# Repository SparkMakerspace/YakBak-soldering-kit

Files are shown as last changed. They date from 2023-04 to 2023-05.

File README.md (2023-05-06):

---
layout: page
title: YakSpark Soldering Kit
permalink: /index.html
---

## About
This project is intended to act as a short introduction to soldering, as well as to act as a platform for exploring audio inputs/outputs with Arduino.

## Components
* Seeed Studio XIAO ESP32C3 ([source](https://www.seeedstudio.com/Seeed-XIAO-ESP32C3-p-5431.html))
* Electret Microphone Amp Module (or clone)
* Adafruit 2130 - PAM8302 (or clone)
* 10Ω resistor (THT)
* 100nf ceramic capacitor
* 8Ω 0.5W Speaker ([source](https://www.harfington.com/products/p-1077007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))

## Assembly
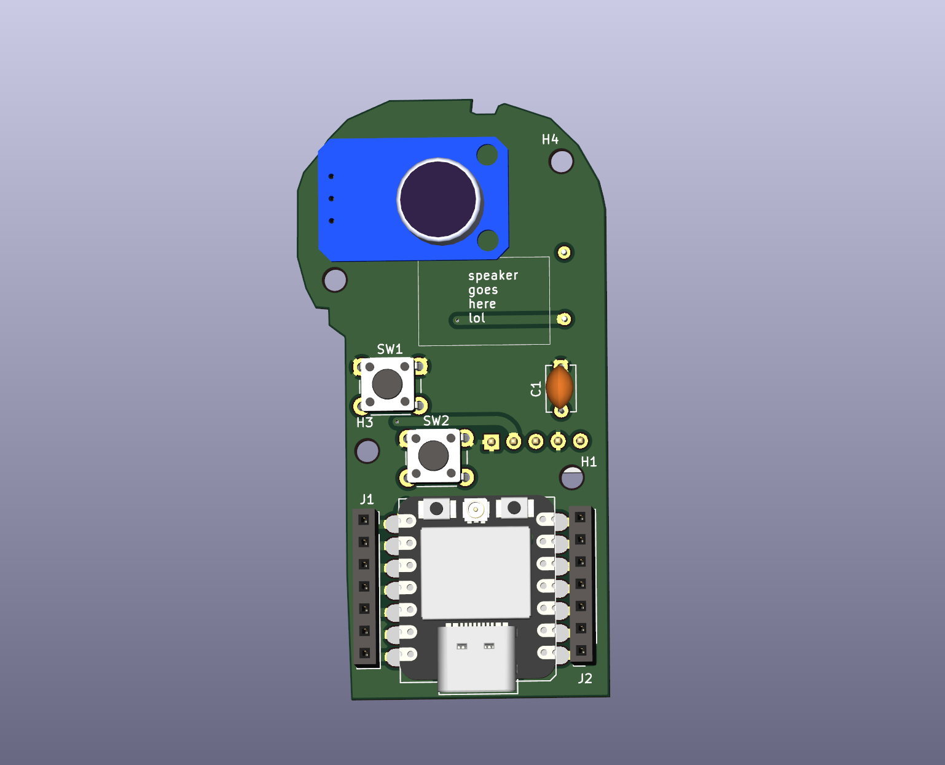
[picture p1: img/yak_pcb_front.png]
YakSpark front

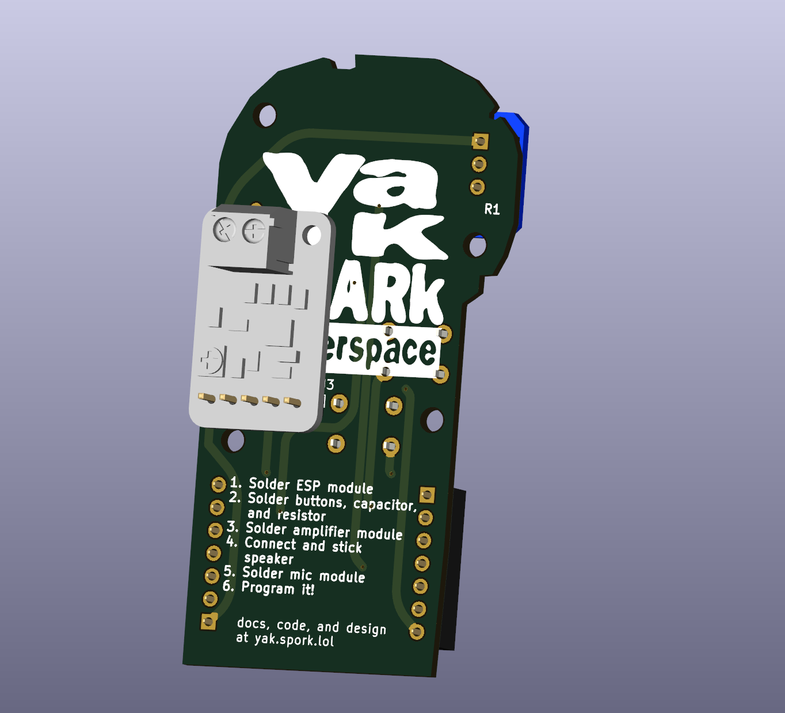
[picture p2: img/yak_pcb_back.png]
YakSpark back


## PCB
The PCB for this project was designed in KiCAD 7.

## Code
Download this repository and open the [software](https://github.com/SparkMakerspace/YakBak-soldering-kit/tree/main/software/test%20software) directory to find the firmware source. The firmware is intended to be modified and flashed with [PlatformIO](https://platformio.org/).

## Enclosure
The YakSpark enclosure is intended to be 3D printed and was designed in FreeCAD. Source, STEP, and STL files are found in the [enclosure](https://github.com/SparkMakerspace/YakBak-soldering-kit/tree/main/enclosure) directory. 
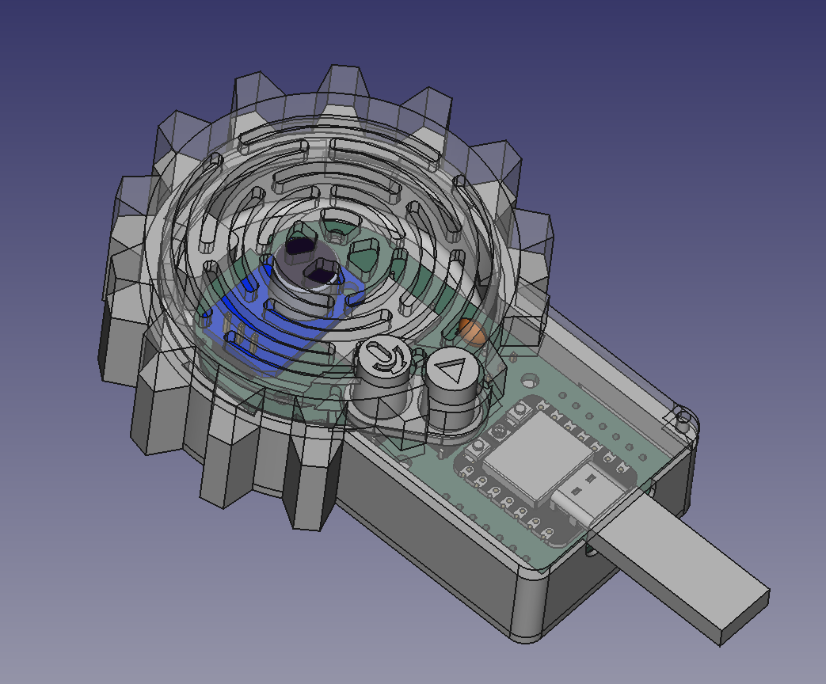
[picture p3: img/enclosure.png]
enclosure


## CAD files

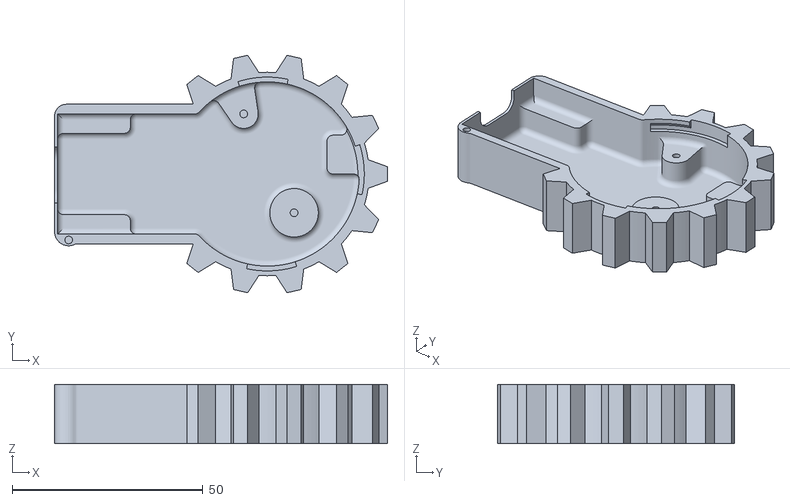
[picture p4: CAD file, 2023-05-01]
enclosure/CAD exports/Yak Spark Assembly v1.0-Lower Case_001.stl
87.3 x 62.2 x 15.5

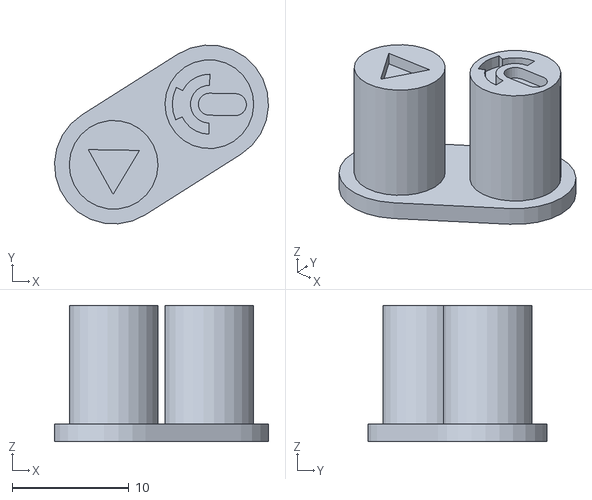
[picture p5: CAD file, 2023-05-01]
enclosure/CAD exports/Yak Spark Assembly v1.0-Buttons_001.stl
18.4 x 15.3 x 11.7

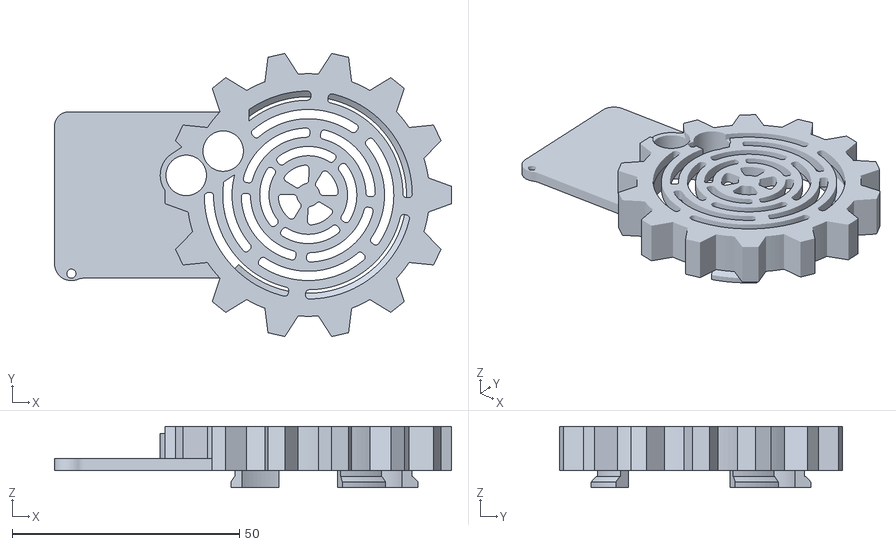
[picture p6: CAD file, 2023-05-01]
enclosure/CAD exports/Yak Spark Assembly v1.0-Upper Case_001.stl
87.3 x 62.2 x 13.5

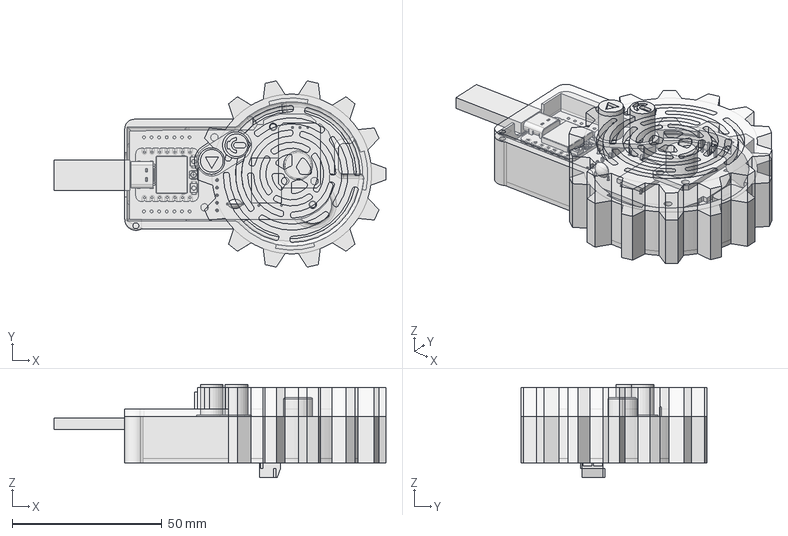
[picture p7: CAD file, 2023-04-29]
enclosure/Yak Spark Assembly v1.0.FCStd
110.9 x 62.2 x 31.2 mm
Lower Case_001
Yak Spark Board_001
Upper Case_001
Buttons_001

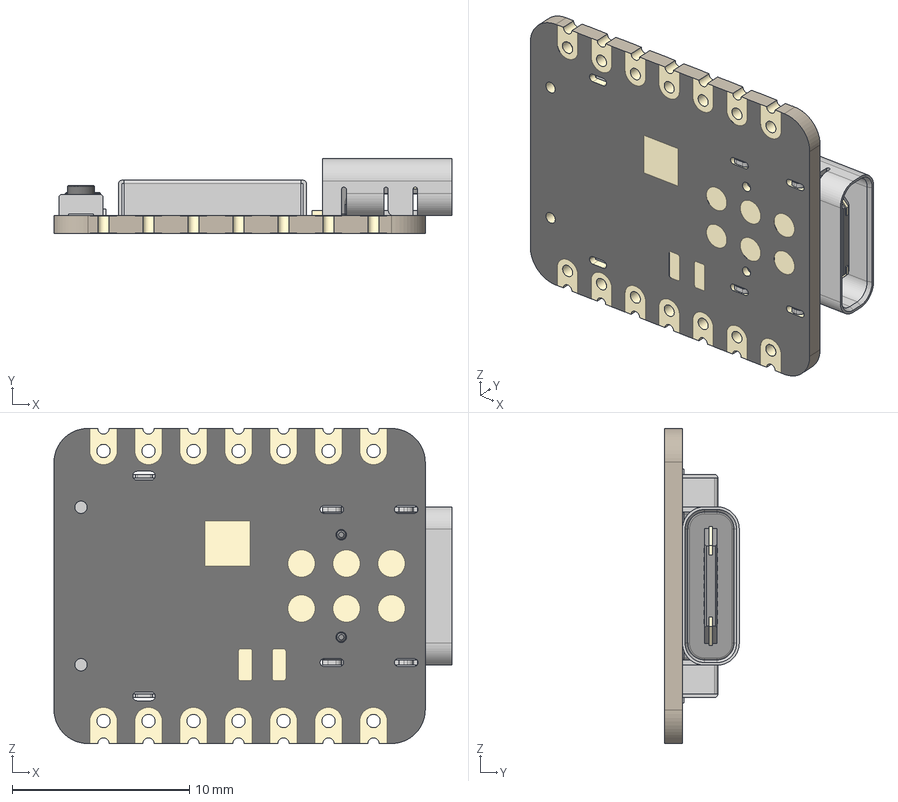
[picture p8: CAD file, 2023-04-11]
3d/Seeed Studio XIAO-ESP32-C3.step
22.5 x 4.21 x 17.8 mm
BOSS-EXTRUDE14_8_
BOSS-EXTRUDE7_4_
BOSS-EXTRUDE7_3_
BOSS-EXTRUDE14_4_
BOSS-EXTRUDE14_2_
BOSS-EXTRUDE14_11_
BOSS-EXTRUDE7_7_
BOSS-EXTRUDE14_9_
BOSS-EXTRUDE14_3_
BOSS-EXTRUDE14_7_
MIRROR2
BOSS-EXTRUDE14_5_
BOSS-EXTRUDE14_12_
BOSS-EXTRUDE7_8_
BOSS-EXTRUDE7_1_
BOSS-EXTRUDE14_10_
BOSS-EXTRUDE7_9_
BOSS-EXTRUDE14_6_
BOSS-EXTRUDE14_1_
BOSS-EXTRUDE7_6_
BOSS-EXTRUDE7_2_
CUT-EXTRUDE5
BOSS-EXTRUDE7_5_
U.FL Connector v1
Button (1) x 2
Shield

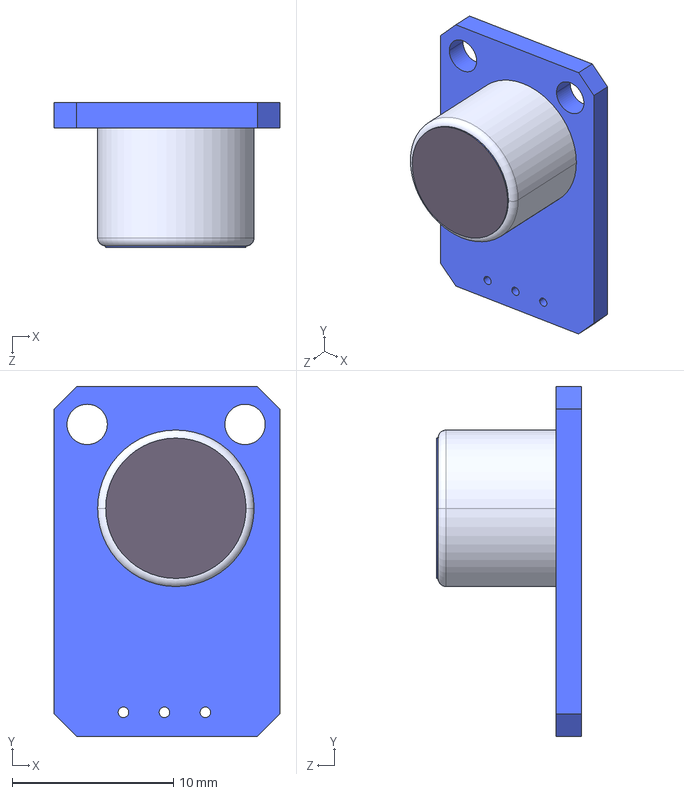
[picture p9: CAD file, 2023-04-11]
3d/max4466_mic_amp.STEP
14.0 x 21.7 x 9.00 mm

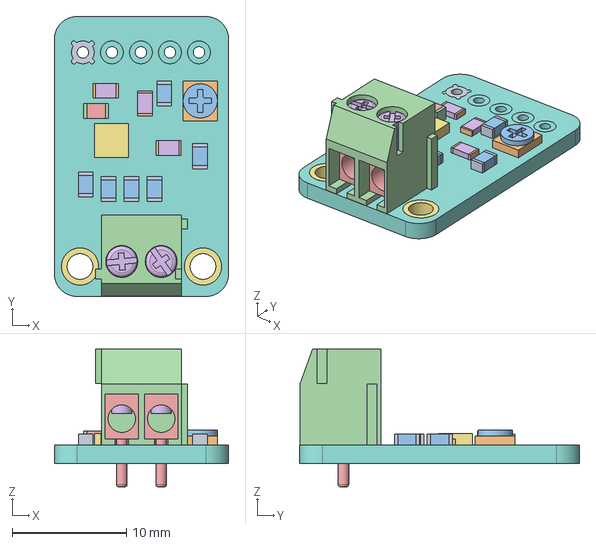
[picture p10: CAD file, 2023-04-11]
3d/adafruit_2130 v1.step
15.3 x 24.5 x 12.1 mm

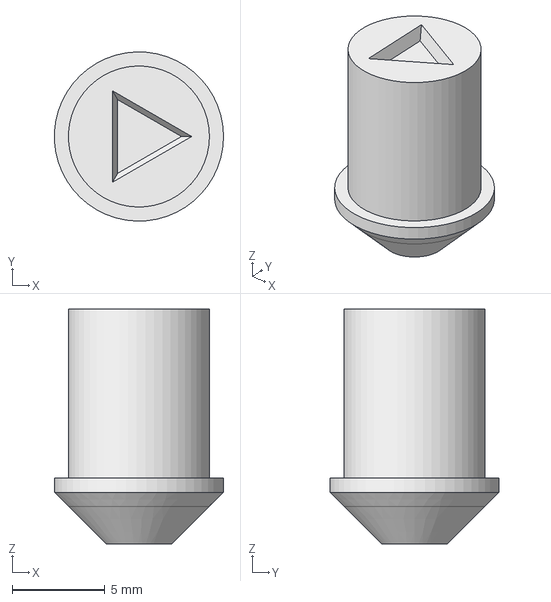
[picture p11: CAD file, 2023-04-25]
enclosure/Play Button.FCStd
9.14 x 9.14 x 12.7 mm

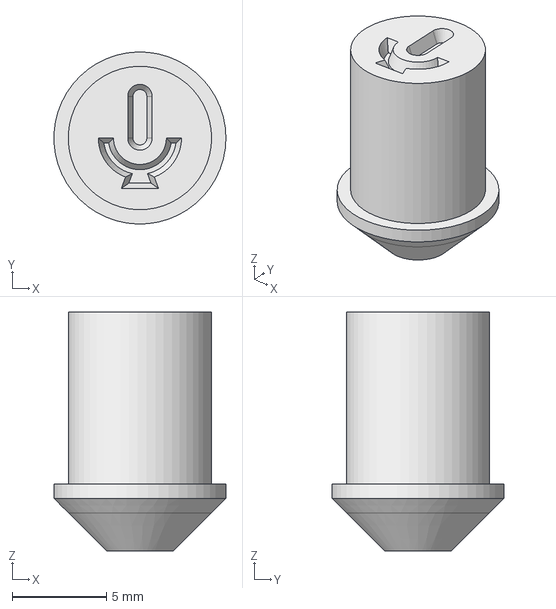
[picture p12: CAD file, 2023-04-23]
enclosure/Record Button.FCStd
9.14 x 9.14 x 12.7 mm

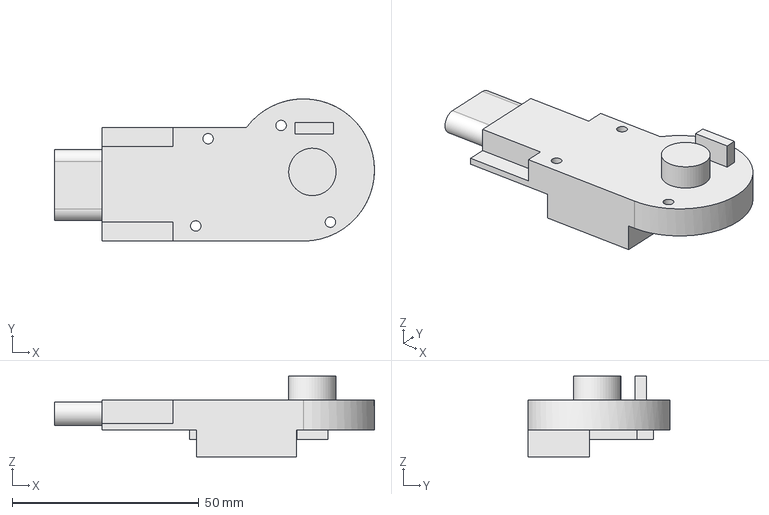
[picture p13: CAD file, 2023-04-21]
enclosure/Space Reservation.FCStd
85.7 x 38.1 x 21.6 mm

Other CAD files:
enclosure/Buttons.FCStd
enclosure/Upper Case.FCStd
enclosure/Lower Case.FCStd
enclosure/CAD exports/Buttons step.step
enclosure/CAD exports/Upper Case step.step
enclosure/CAD exports/Lower Case step.step
enclosure/CAD exports/Play Button Step.step
enclosure/CAD exports/Record Button Step.step
enclosure/CAD exports/Buttons step.stl
enclosure/CAD exports/Lower Case step.stl
enclosure/CAD exports/Upper Case step.stl
enclosure/Yak Spark Board.FCStd

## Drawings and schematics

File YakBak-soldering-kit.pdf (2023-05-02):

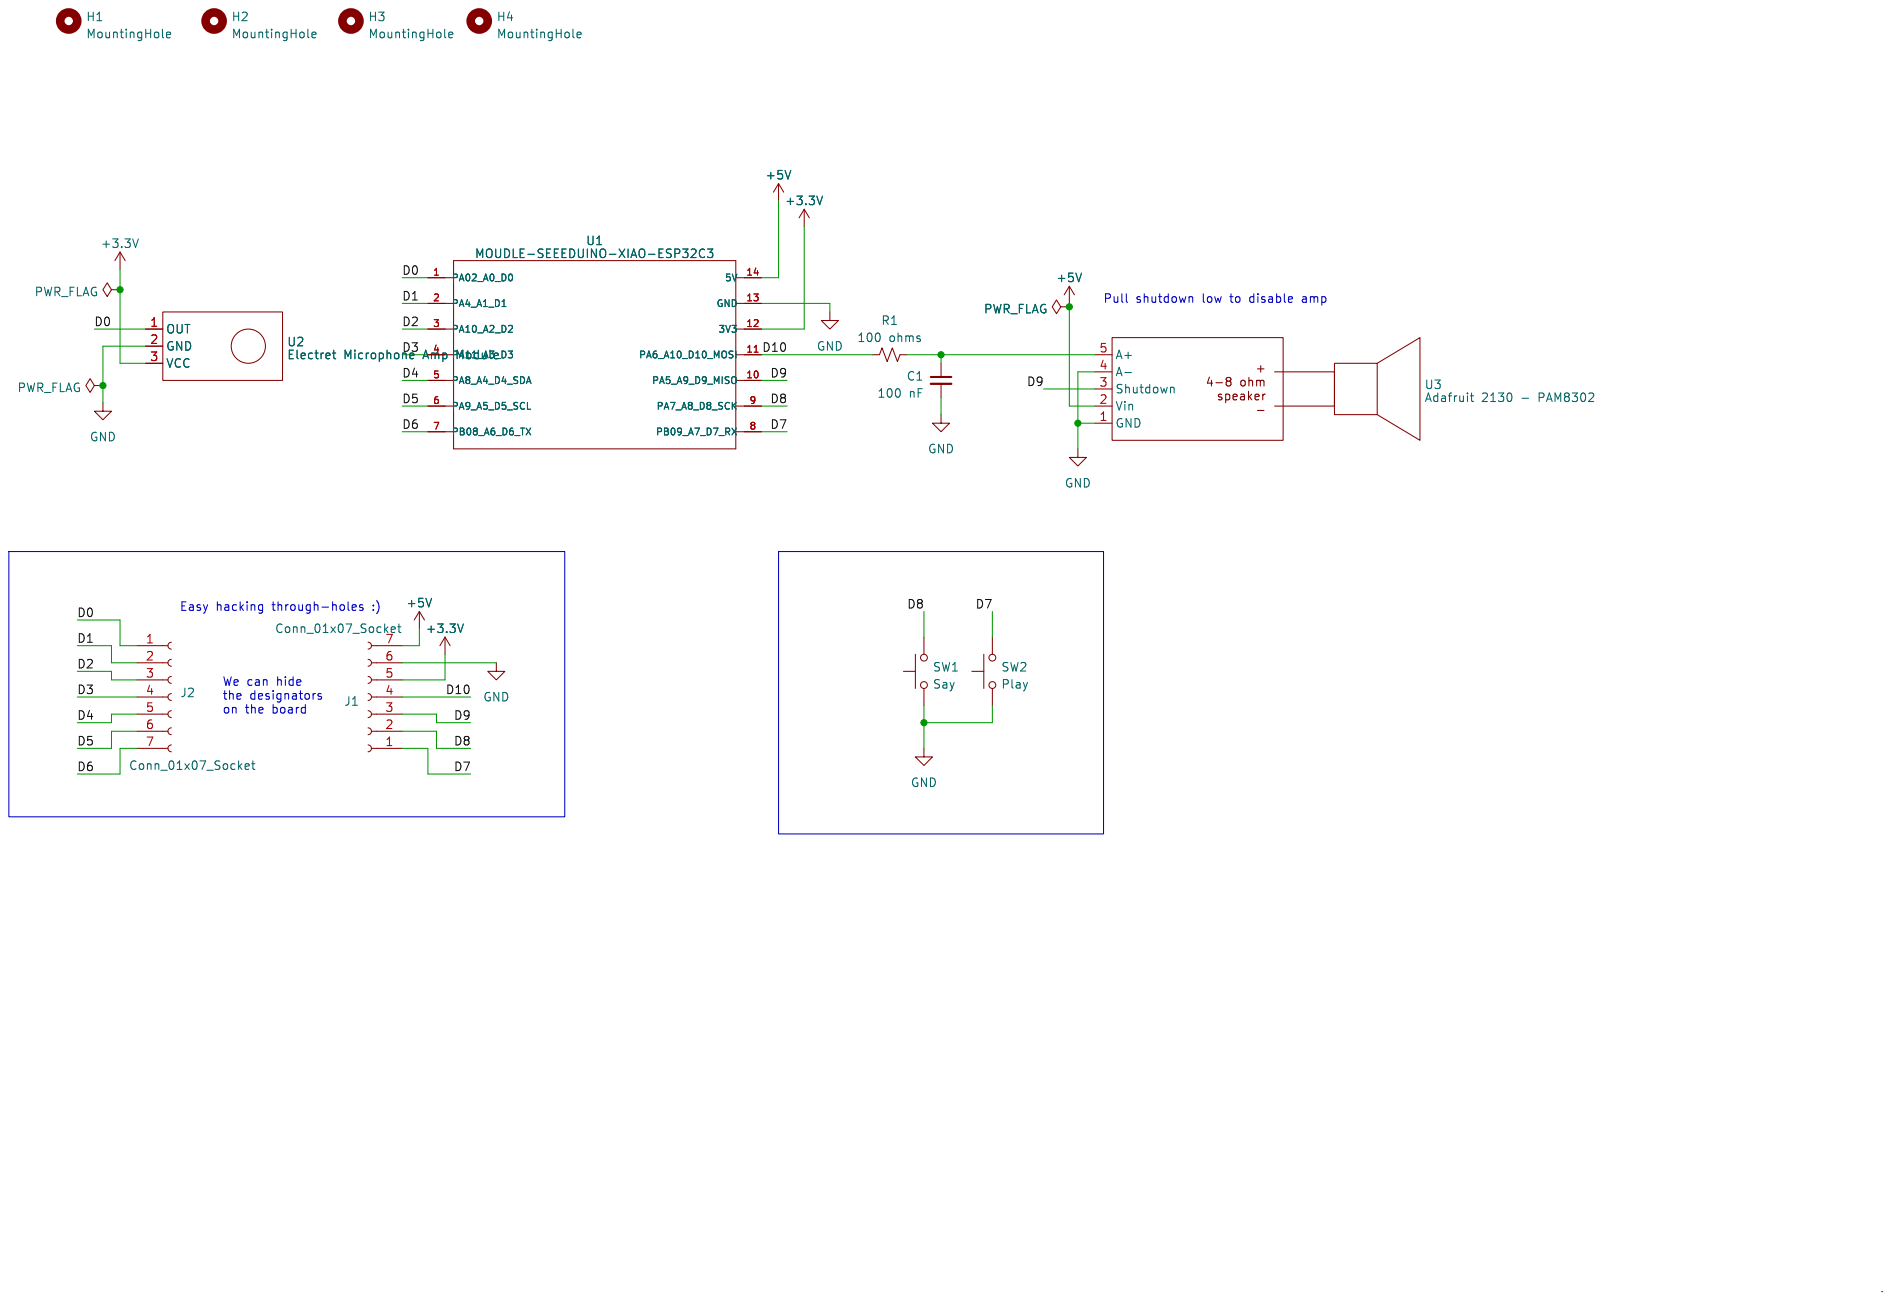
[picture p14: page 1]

the designators on the board

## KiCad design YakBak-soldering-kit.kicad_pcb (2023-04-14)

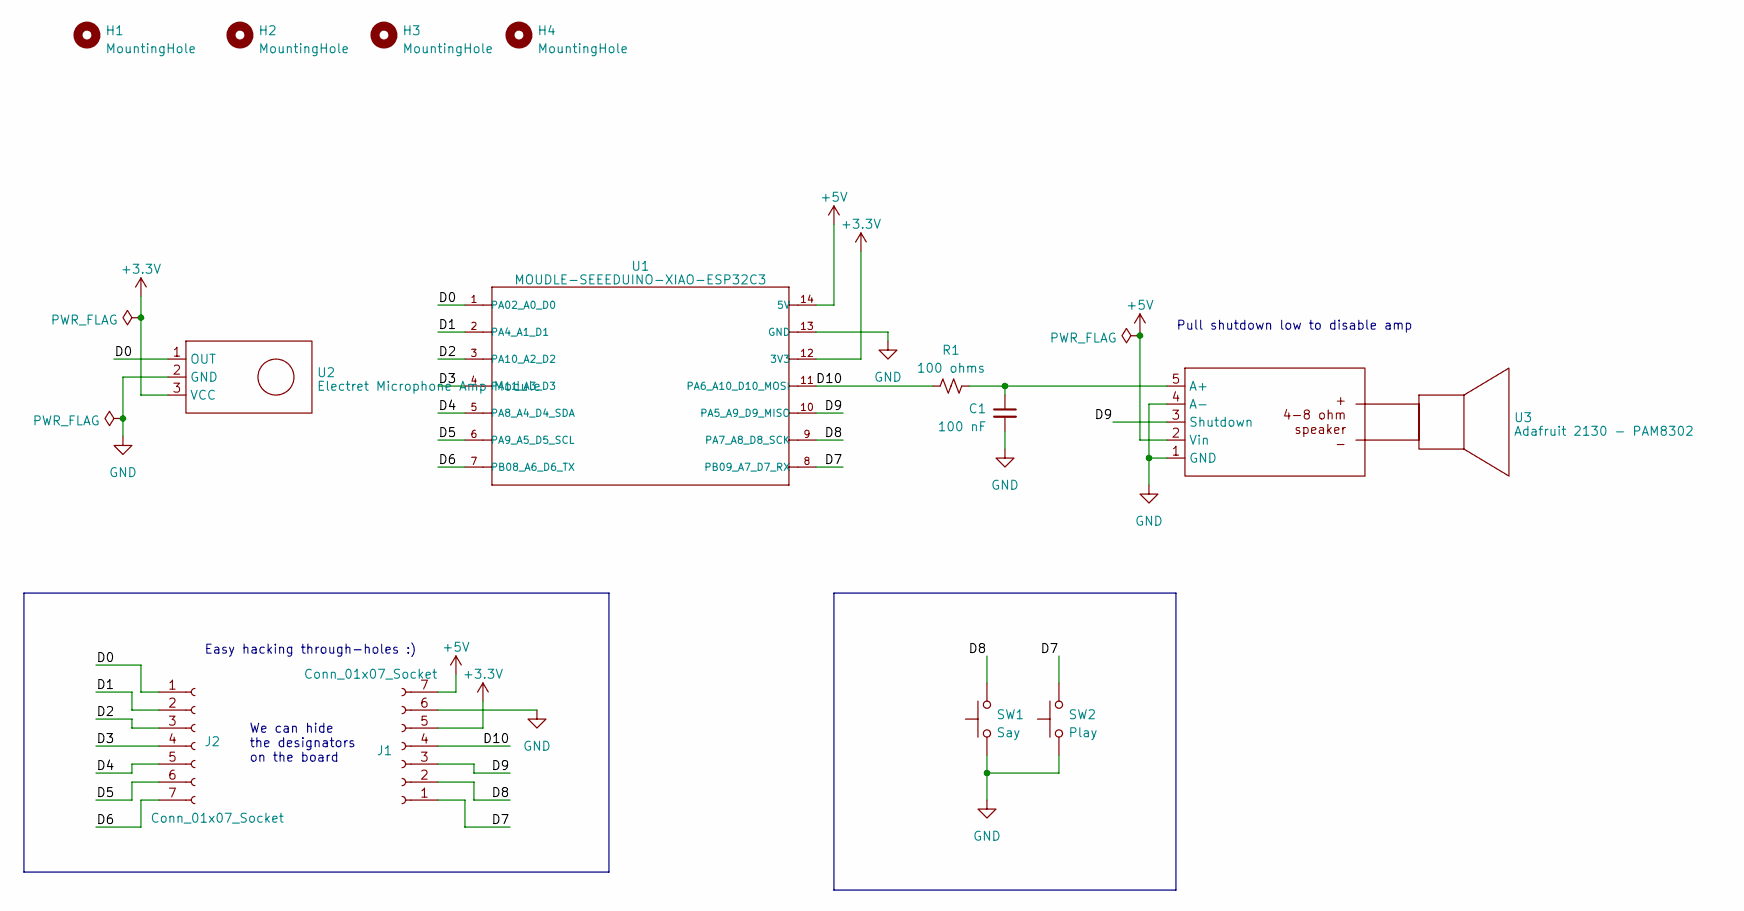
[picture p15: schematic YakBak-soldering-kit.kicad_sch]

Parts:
C1: 100 nF; C_Disc_D5.1mm_W3.2mm_P5.00mm
H1, H2, H3, H4: MountingHole; MountingHole_2.5mm
J1, J2: Conn_01x07_Socket; PinSocket_1x07_P2.54mm_Vertical
R1: 100 ohms; R_Axial_DIN0204_L3.6mm_D1.6mm_P7.62mm_Horizontal
SW1: Say; SW_PUSH_6mm
SW2: Play; SW_PUSH_6mm
U1: MOUDLE-SEEEDUINO-XIAO-ESP32C3; MOUDLE14P-SMD-2.54-21X17.8MM
U2: Electret Microphone Amp Module; PinSocket_1x03_P2.54mm_Vertical
U3: Adafruit 2130 - PAM8302; PinHeader_1x05_P2.54mm_Vertical

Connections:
+3.3V: J1.5, U1.12 (3V3), U2.3 (VCC)
+5V: J1.7, U1.14 (5V), U3.2 (Vin)
/D0: J2.1, U1.1 (PA02_A0_D0), U2.1 (OUT)
/D1: J2.2, U1.2 (PA4_A1_D1)
/D2: J2.3, U1.3 (PA10_A2_D2)
/D3: J2.4, U1.4 (PA11_A3_D3)
/D4: J2.5, U1.5 (PA8_A4_D4_SDA)
/D5: J2.6, U1.6 (PA9_A5_D5_SCL)
/D6: J2.7, U1.7 (PB08_A6_D6_TX)
/D7: J1.1, SW2.2, U1.8 (PB09_A7_D7_RX)
/D8: J1.2, SW1.2, U1.9 (PA7_A8_D8_SCK)
/D9: J1.3, U1.10 (PA5_A9_D9_MISO), U3.3 (Shutdown)
/D10: J1.4, R1.1, U1.11 (PA6_A10_D10_MOSI)
GND: C1.2, J1.6, SW1.1, SW2.1, U1.13 (GND), U2.2 (GND), U3.1 (GND), U3.4 (A-)
unnamed: C1.1, R1.2, U3.5 (A+)

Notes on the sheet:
We can hide the designators on the board
Pull shutdown low to disable amp
Easy hacking through-holes :)

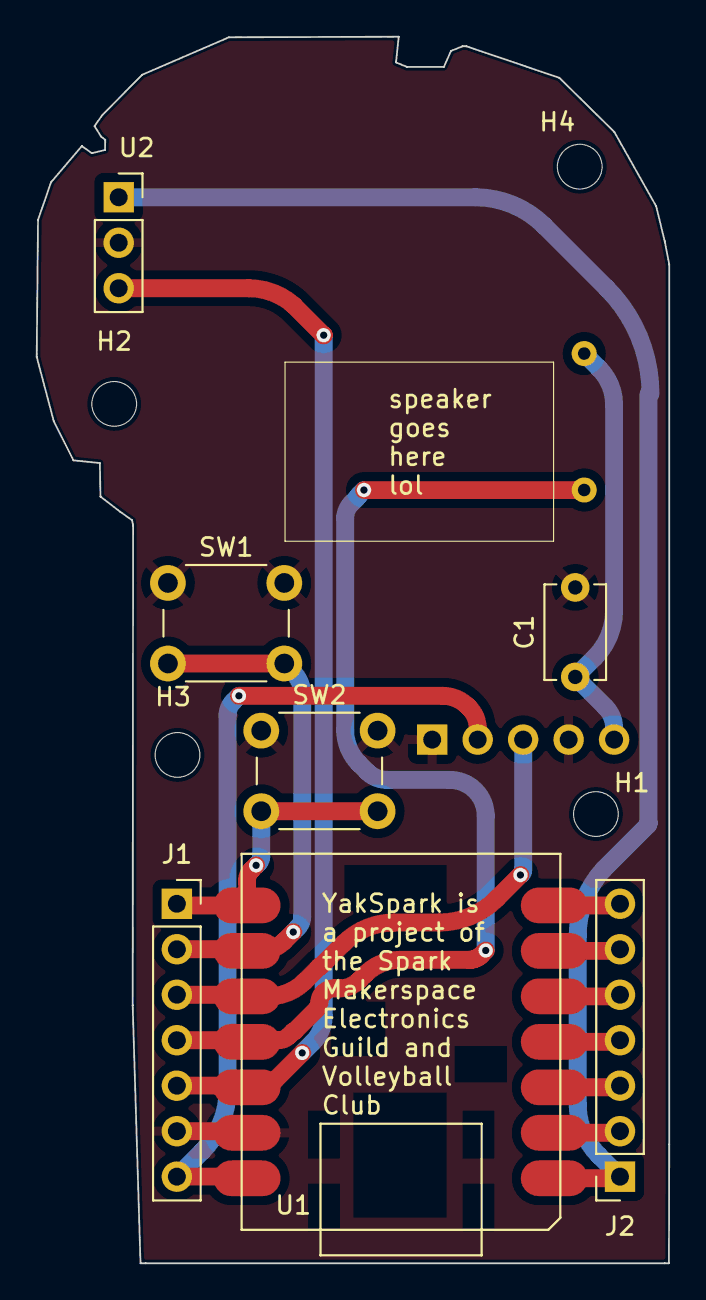
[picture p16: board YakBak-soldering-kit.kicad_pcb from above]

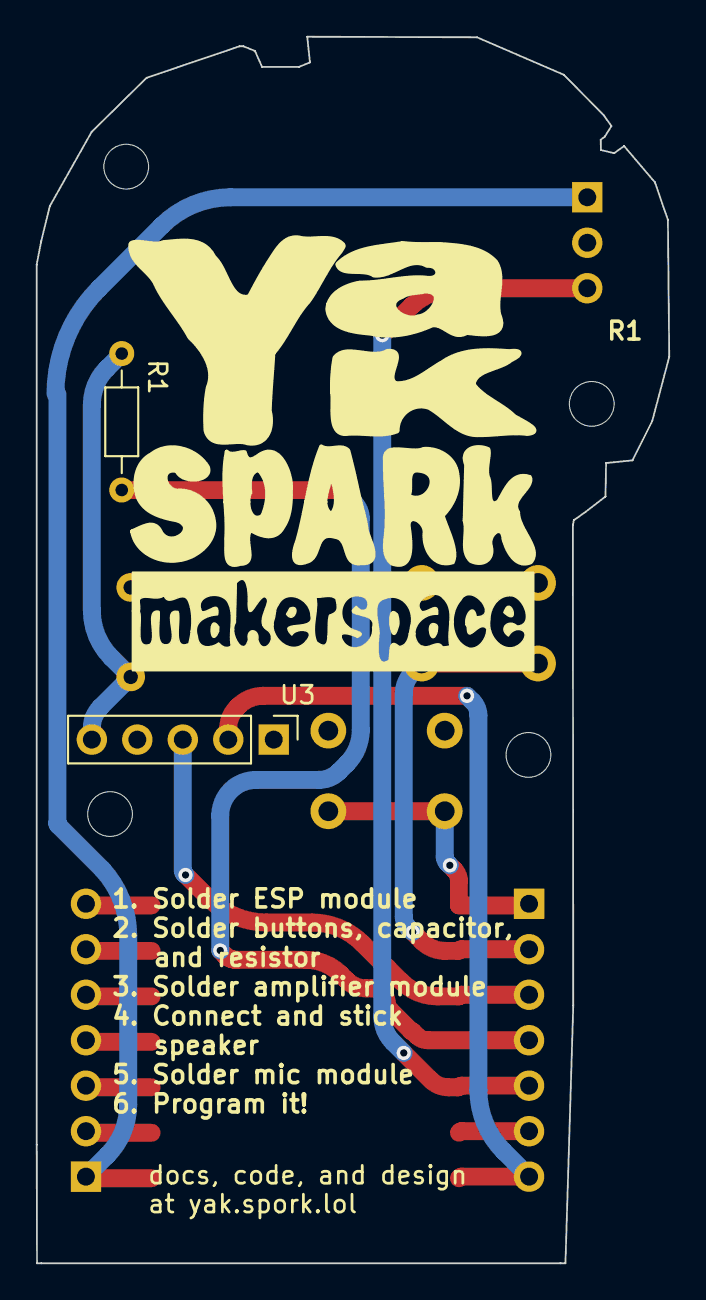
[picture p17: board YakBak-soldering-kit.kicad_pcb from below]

Board: 2 copper layers, 35.3 x 68.5 mm, 13 parts (2 on the bottom side), 15 nets.

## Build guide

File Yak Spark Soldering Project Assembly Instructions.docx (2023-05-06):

# Yak Spark Soldering Project Assembly Instructions

# 1. Solder the Xiao ESP32C3 module to U1

Tack the module into play by soldering only the top right pad. While applying heat to melt the solder, align the module and then remove heat. If you need to you can reheat the solder and re-align it. Once happy with the alignment, solder the remaining pads.

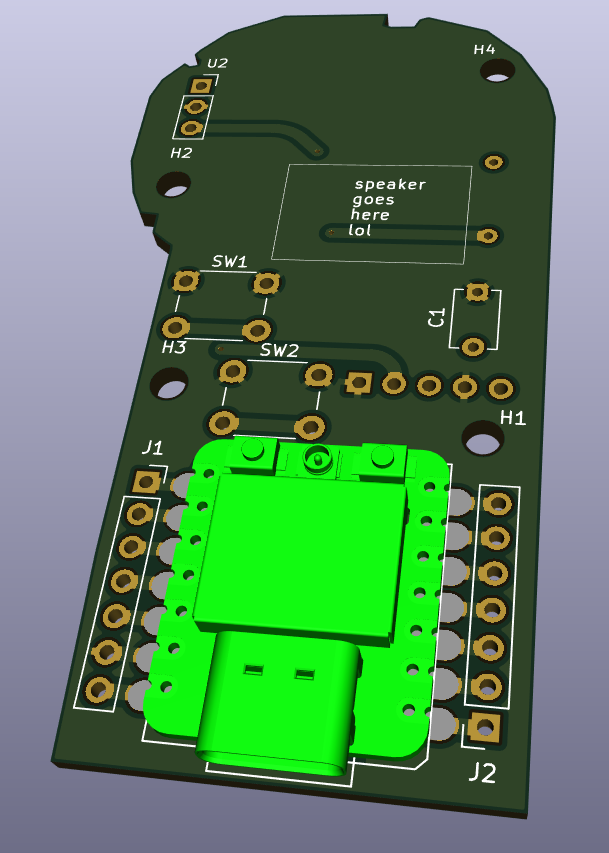
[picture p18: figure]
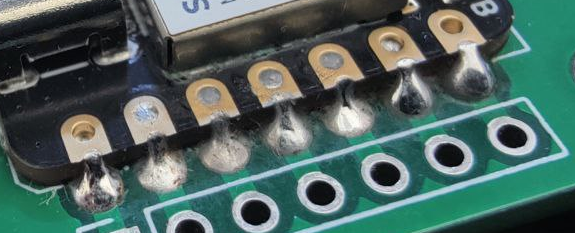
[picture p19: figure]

# 2. Solder the Capacitor and Resistor to C1 and R1

Push the leads through the holes and bend them out slightly to hold the part in place. Flip the board over and solder each lead. Then clip the leads.

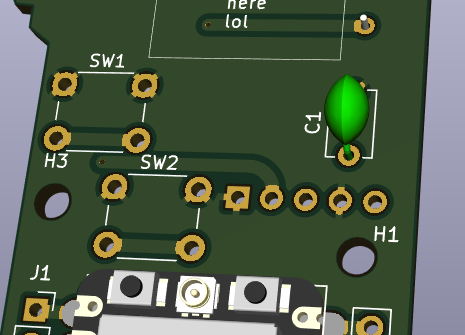
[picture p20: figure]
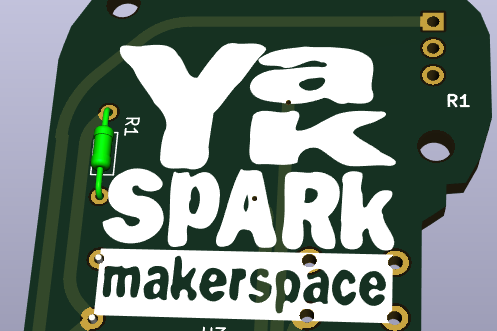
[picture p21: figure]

# 3. Solder the Buttons to SW1 and SW2

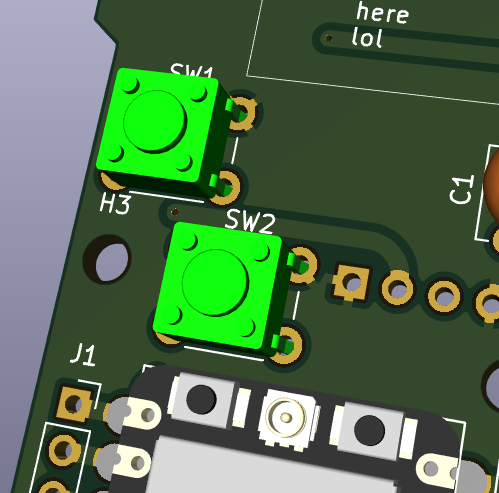
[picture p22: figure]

# 4. Solder the Speaker to the Amplifier Board

Polarity doesn’t matter. It’s easiest to do this step while the amplifier is not yet soldered to the Yak Spark board.

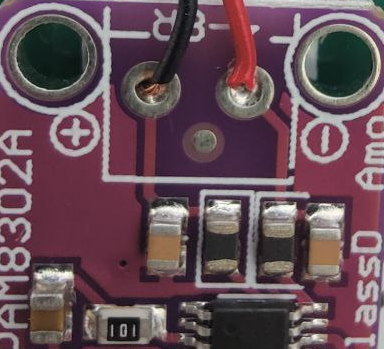
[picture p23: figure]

# 5. Solder the Amplifier Board to U3

This is a two step process. Step one is to solder the pin header to the amplifier board and then solder them to the Yak Spark board.

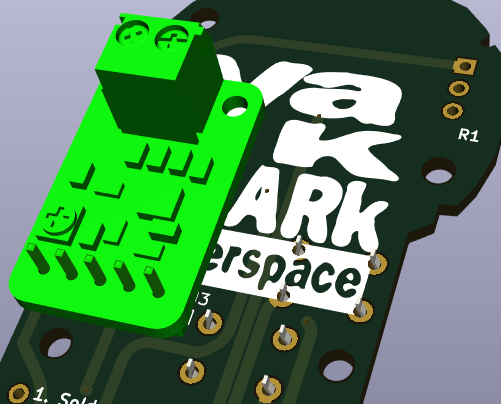
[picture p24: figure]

# 6. Solder the Microphone Module to U2

Similar to the amplifier board, solder the pin header to the microphone board and then solder those to the Yak Spark board.

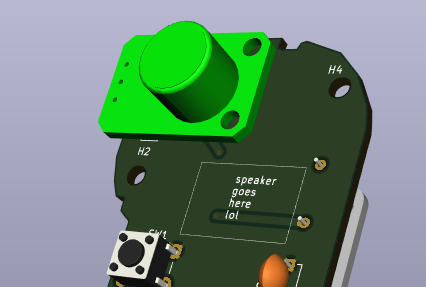
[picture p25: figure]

# 7. Stick the Speaker to the spot on the front of the board

Peel the cover off of the adhesive and stick it right onto the board.

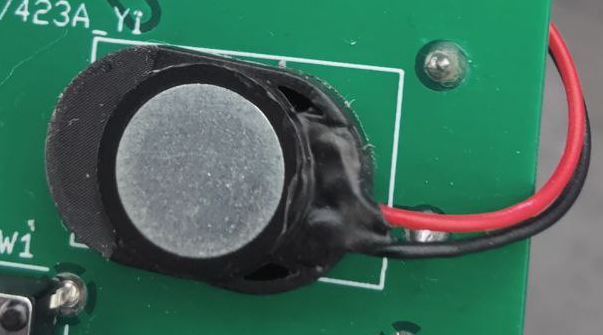
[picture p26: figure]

# 8. Program it

Go to the KEEPER OF THE CODE and get the board programmed. See https://yak.spark.lol for more information about this project including the source code so you can hack it at home!

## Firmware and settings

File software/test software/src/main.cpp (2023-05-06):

#include <Arduino.h>
#include <SPIFFS.h>

// Tweak these as desired
#define SERIAL_EN false      // Disable when we're ready for "production"
#define PWM_FREQ 80000       // This isn't exactly what it'll be, but that's totally fine.
#define SAMPLE_FREQ 8000     // Input and output samples/second
#define CLOCK_DIVIDER 80     // the APB clock (used to time stuff) should be running at 80MHz. This divider lets us use smaller numbers :)
#define SAMPLE_COUNT_FUDGE 0 // ehhh nobody's perfect. Our sample rate might need this (it's in counts so use numbers like -3 or -5 if needed)

// don't change these ones
#define COUNT_PER_SAMPLE (APB_CLK_FREQ / CLOCK_DIVIDER / SAMPLE_FREQ) + SAMPLE_COUNT_FUDGE // Just a pre-processor calculation to simplify runtime
#define FORMAT_SPIFFS_IF_FAILED true

// Play state variable enumerations - yes, this is dumb, but whatever
#define PLAY_IDLE 0
#define ABOUT_TO_PLAY 1
#define PLAYING 2
#define FINISHED_PLAYING 3

uint8_t analogOut = 10;
uint8_t sayButton = 8;
uint8_t playButton = 20;
uint8_t amplifierShutdown = 9;
uint8_t microphone = 2;
hw_timer_t *timer = NULL;
volatile SemaphoreHandle_t timerSemaphore;
portMUX_TYPE timerMux = portMUX_INITIALIZER_UNLOCKED;

// used for button state and edge detection
boolean sayPressed = false;
boolean wasSayPressed = false;
boolean sayJustPressed = false;
boolean sayJustReleased = false;
boolean playPressed = false;
boolean wasPlayPressed = false;
boolean playJustPressed = false;

// used to store data in memory temporarily
uint8_t recordBuffer[2048];
uint16_t recordBufferSize;
uint8_t playBuffer[2048];
uint16_t playBufferSize;

// used for SPIFFS formatting
bool formatted = false;

// used to keep time
uint64_t useconds;

// first time that we write to a file, we need to use a different function
boolean firstWrite;

// state variable for playing sounds
uint8_t playState;

// and the file handle for playing sounds
File playFile;

///////////////////////////////////////////////////
//  THIS SECTION IS FOR SPIFFS   //////////////////
///////////////////////////////////////////////////

void listDir(fs::FS &fs, const char *dirname, uint8_t levels)
{
  Serial.printf("Listing directory: %s\n", dirname);

  File root = fs.open(dirname);
  if (!root)
  {
    Serial.println("Failed to open directory");
    return;
  }
  if (!root.isDirectory())
  {
    Serial.println("Not a directory");
    return;
  }

  File file = root.openNextFile();
  while (file)
  {
    if (file.isDirectory())
    {
      Serial.print("  DIR : ");
      Serial.print(file.name());
      time_t t = file.getLastWrite();
      struct tm *tmstruct = localtime(&t);
      Serial.printf("  LAST WRITE: %d-%02d-%02d %02d:%02d:%02d\n", (tmstruct->tm_year) + 1900, (tmstruct->tm_mon) + 1, tmstruct->tm_mday, tmstruct->tm_hour, tmstruct->tm_min, tmstruct->tm_sec);
      if (levels)
      {
        listDir(fs, file.path(), levels - 1);
      }
    }
    else
    {
      Serial.print("  FILE: ");
      Serial.print(file.name());
      Serial.print("  SIZE: ");
      Serial.print(file.size());
      time_t t = file.getLastWrite();
      struct tm *tmstruct = localtime(&t);
      Serial.printf("  LAST WRITE: %d-%02d-%02d %02d:%02d:%02d\n", (tmstruct->tm_year) + 1900, (tmstruct->tm_mon) + 1, tmstruct->tm_mday, tmstruct->tm_hour, tmstruct->tm_min, tmstruct->tm_sec);
    }
    file = root.openNextFile();
  }
}

void readFile(fs::FS &fs, const char *path)
{
  Serial.printf("Reading file: %s\n", path);

  File file = fs.open(path);
  if (!file)
  {
    Serial.println("Failed to open file for reading");
    return;
  }
  while (file.available())
  {
    Serial.printf("%d\t", file.read());
  }
  file.close();
}

void writeFile(fs::FS &fs, const char *path, const uint8_t *buffer, const uint16_t buffsize)
{
  Serial.printf("Writing file: %s with buffer size: %d\n", path, buffsize);

  File file = fs.open(path, FILE_WRITE);
  if (!file)
  {
    Serial.println("Failed to open file for writing");
    return;
  }
  if (!file.write(buffer, buffsize))
  {
    Serial.println("Write failed");
  }
  file.close();
}

void appendFile(fs::FS &fs, const char *path, const uint8_t *buffer, const uint16_t buffsize)
{
  Serial.printf("Appending to file: %s\n", path);

  File file = fs.open(path, FILE_APPEND);
  if (!file)
  {
    Serial.println("Failed to open file for appending");
    return;
  }
  if (!file.write(buffer, buffsize))
  {
    Serial.println("Append failed");
  }
  file.close();
}

void deleteFile(fs::FS &fs, const char *path)
{
  Serial.printf("Deleting file: %s\n", path);
  if (fs.remove(path))
  {
    Serial.println("File deleted");
  }
  else
  {
    Serial.println("Delete failed");
  }
}

/////////////////////////////////////////////////////////////////
//   Ok. The SPIFFS section is over now.  ///////////////////////
/////////////////////////////////////////////////////////////////

void setup()
{
  // Serial first
  if (SERIAL_EN)
  {
    Serial.begin();
    delay(5000); // delay so we have time to connect
  }

  // Pinmodes
  pinMode(analogOut, OUTPUT);
  pinMode(sayButton, INPUT_PULLUP);
  pinMode(playButton, INPUT_PULLUP);
  pinMode(amplifierShutdown, OUTPUT);
  pinMode(microphone, ANALOG);

  // turn off the amplifier
  digitalWrite(amplifierShutdown, LOW);

  // Initialize SPIFFS
  if (!SPIFFS.begin(FORMAT_SPIFFS_IF_FAILED))
  {
    Serial.println("SPIFFS Mount Failed");
    return;
  }

  // set up the ADC stuff
  analogReadResolution(8);

  // Create semaphore to inform us when the timer has fired
  timerSemaphore = xSemaphoreCreateBinary();

  // Set the PWM frequency, get the actual PWM frequency back
  uint32_t clockFreq = sigmaDeltaSetup(analogOut, 0, PWM_FREQ);
  // Print out the frequency via serial
  if (clockFreq == 0)
  {
    (SERIAL_EN) ? Serial.println("Could not set PWM clock frequency") : 0;
  }
  else
  {
    (SERIAL_EN) ? Serial.printf("PWM clock frequency: %d\n", clockFreq) : 0;
  }
  // No output yet
  sigmaDeltaWrite(0, 0);

  // Setup timer at the sample rate
  timer = timerBegin(0, CLOCK_DIVIDER, true);

  // initialize a few variables
  recordBufferSize = 0;
  firstWrite = true;
  playState = PLAY_IDLE;
}

void loop()
{
  // put your main code here, to run repeatedly:
  //(SERIAL_EN)? Serial.printf("Last time: %d\n",timerReadMicros(timer)-useconds):0;
  // capture current time
  useconds = timerReadMicros(timer);
  //(SERIAL_EN)? Serial.printf("This time: %d\n",timerReadMicros(timer)-useconds):0;
  // button push states and edges
  wasSayPressed = sayPressed;
  sayPressed = !digitalRead(sayButton);
  sayJustPressed = !wasSayPressed && sayPressed;
  sayJustReleased = wasSayPressed && !sayPressed;
  wasPlayPressed = playPressed;
  playPressed = !digitalRead(playButton);
  playJustPressed = !wasPlayPressed && playPressed;

  //-------------------------//
  // Say button stuff        //
  //-------------------------//
  // DON'T DO ANYTHING WHILE PLAYING
  if (playState == PLAY_IDLE)
  {
    // Delete the old data if the say button was just pressed
    if (sayJustPressed)
    {
      deleteFile(SPIFFS, "/audio.wav");
      (SERIAL_EN) ? Serial.printf("Recording now!\n") : 0;
      // reset the firstWrite var!
      firstWrite = true;
    }
    // Record for as long as the say button is pressed
    if (sayPressed)
    {
      // stuff it in the buffer
      recordBuffer[recordBufferSize] = analogRead(microphone);
      (SERIAL_EN) ? Serial.printf("Sample: %d\n", recordBuffer[recordBufferSize]) : 0;
      // and then index the next spot in the buffer
      // this is basically a pointer
      recordBufferSize++;
    }
    // Every now and then we need to dump the data to a file - oh also when say is released.
    if (recordBufferSize >= 1024 || sayJustReleased)
    {
      (SERIAL_EN) ? Serial.printf("Hold on - let me write this down.\nBuffer size: %d\n", recordBufferSize) : 0;
      // different funtion for the first write vs appends
      (firstWrite) ? writeFile(SPIFFS, "/audio.wav", recordBuffer, recordBufferSize) : appendFile(SPIFFS, "/audio.wav", recordBuffer, recordBufferSize);
      // ok, now only append.
      firstWrite = false;
      // fun fact - this clears the buffer by resetting the "pointer"
      recordBufferSize = 0;
    }
    // When the say button is released, we can helpfully show we recorded something via serial.
    if (sayJustReleased && SERIAL_EN)
    {
      Serial.printf("Stopped recording. Here's the results\n");
      readFile(SPIFFS, "/audio.wav");
    }
  }
  //-------------------------//
  // End of Say button stuff //
  //-------------------------//

  //--------------------------//
  // Play button stuff        //
  //--------------------------//
  // idle:
  if (playState == PLAY_IDLE)
  {
    // state = aboutToPlay if play button just pressed
    if (playJustPressed)
    {
      playState = ABOUT_TO_PLAY;
    }
  }

  // aboutToPlay:
  if (playState == ABOUT_TO_PLAY)
  {
    (SERIAL_EN) ? Serial.printf("Oh boy, let's get ready to play!\n") : 0;
    // open the file
    playFile = SPIFFS.open("/audio.wav");
    // turn on the amp
    digitalWrite(amplifierShutdown, HIGH);
    // state = playing
    playState = PLAYING;
  }

  // playing:
  if (playState == PLAYING)
  {
    if (playFile.available())
    {
      // read one byte from the file
      static char playBuffer;
      playFile.readBytes(&playBuffer, 1);
      (SERIAL_EN) ? Serial.printf("%d\t", playBuffer) : 0;
      // and write that byte to sigmaDelta
      sigmaDeltaWrite(0, (uint8_t)playBuffer);
    }
    else
    {
      // stop outputting
      sigmaDeltaWrite(0, 0);
      // state = finishedPlaying if no file left
      playState = FINISHED_PLAYING;
    }
  }

  // finishedPlaying:
  if (playState == FINISHED_PLAYING)
  {
    // turn off the amp
    digitalWrite(amplifierShutdown, LOW);
    // close the file
    playFile.close();
    // state = idle
    playState = PLAY_IDLE;
  }
  // //--------------------------//
  // End of Play button stuff //
  //--------------------------//

  // Spin until we should loop again
  while (useconds + COUNT_PER_SAMPLE > timerReadMicros(timer))
  {
    delayMicroseconds(1);
  };
}

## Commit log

2023-04-09 Finished the schematic. Review time!
    [YakBak-soldering-kit.kicad_sch]
2023-04-10 changes to schematic to fix ERC check and addition of PCB edges.
    [YakBak-soldering-kit.kicad_pcb, YakBak-soldering-kit.kicad_sch]
2023-04-11 finished draft layout and updated missing symbols/footprints
    [Seeed Studio XIAO-ESP32-C3.step, YakBak-soldering-kit.kicad_pcb, YakBak-soldering-kit.kicad_sch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]
2023-04-14 added artwork and routed traces
    [YakBak-soldering-kit.kicad_pcb]
2023-04-14 add ground fill to F.Cu
    [YakBak-soldering-kit.kicad_pcb]
2023-04-14 cleaned up, rounded traces, added directions
    [YakBak-soldering-kit.kicad_pcb]
2023-04-14 plot gerber files for R1
    [YakBak-soldering-kit-B_Cu.gbl, YakBak-soldering-kit-B_Mask.gbs, YakBak-soldering-kit-B_Silkscreen.gbo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]
2023-04-14 set grid origin for PCB.
    [YakBak-soldering-kit.kicad_pcb]
2023-04-21 Enclosure 3D files
    This file has the freecad files, step files, and gcode for printing the Yak Spark Enclosure. The gcode has not been tested, use at your own risk.
    [Lower Case step.step, Lower Case.FCStd, Play Button Step.step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]
2023-04-23 Updates to fix interference
    Removed an interference, modified record button to have slightly larger symbol
    [Lower Case step.step, Lower Case.FCStd, Record Button Step.step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]
2023-04-25 Updates from 4/24 meeting
    [Buttons step.step, Buttons.FCStd, Lower Case step.step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]
2023-04-27 add STL files, since Cura doesn't seem to support STEP models.
    [Yak Spark Assembly v1.0-Buttons_001.stl, Yak Spark Assembly v1.0-Lower Case_001.stl, Yak Spark Assembly v1.0-Upper Case_001.stl]
2023-04-29 Mechanical connection updates
    [Buttons step.step, Buttons.FCStd, Lower Case step.step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]
2023-05-01 updated the stl exports
    [Yak Spark Assembly v1.0-Buttons_001.stl, Yak Spark Assembly v1.0-Lower Case_001.stl, Yak Spark Assembly v1.0-Upper Case_001.stl]
2023-05-02 Made a pdf of the schematic and started a test program
2023-05-06 add STL files of enclosure
    [Buttons step.stl, Lower Case step.stl, Upper Case step.stl]
2023-05-06 add images pcb and enclosure
2023-05-06 rename enclosure folder
    [Buttons step.step, Buttons step.stl, Buttons.FCStd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]
2023-05-06 cleanup move of enclosure folder
    [Buttons step.step, Buttons step.stl, Buttons.FCStd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]
2023-05-06 Added photos and assembly instructions
